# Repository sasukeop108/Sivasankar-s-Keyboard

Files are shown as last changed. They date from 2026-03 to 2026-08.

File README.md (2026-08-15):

# Sivasankar's keyboard
One day, I was thinking about making a custom keyboard which would be suitable for me from scratch but that was too costly. After i joined hackclub's stasis i thought why not to build our keyboard as the stasis event funds us. So i started making a custom 75 percent keyboard from scratch using fusion 360 and kicad. I used the layout keycool 84 which had 84 keys in it.
# Built keyboard


# Layout
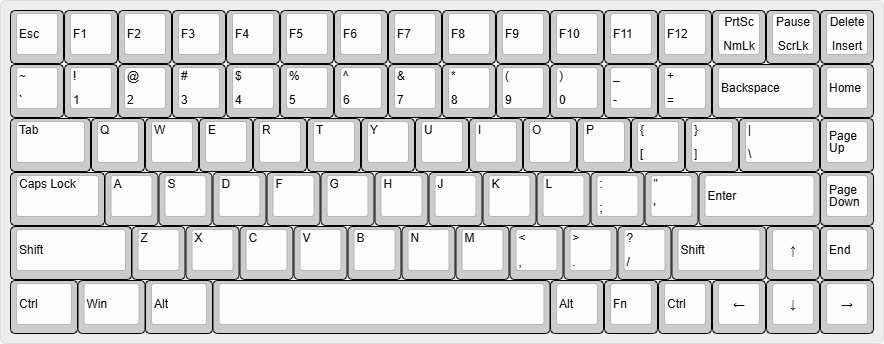
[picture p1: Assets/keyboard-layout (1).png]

# CAD
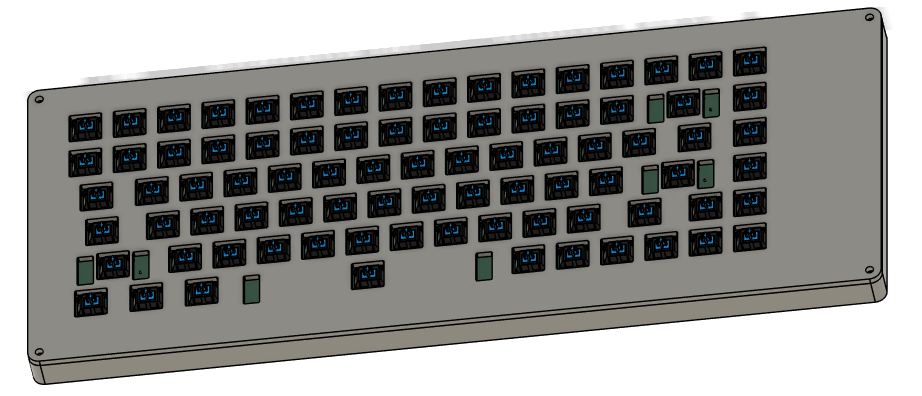
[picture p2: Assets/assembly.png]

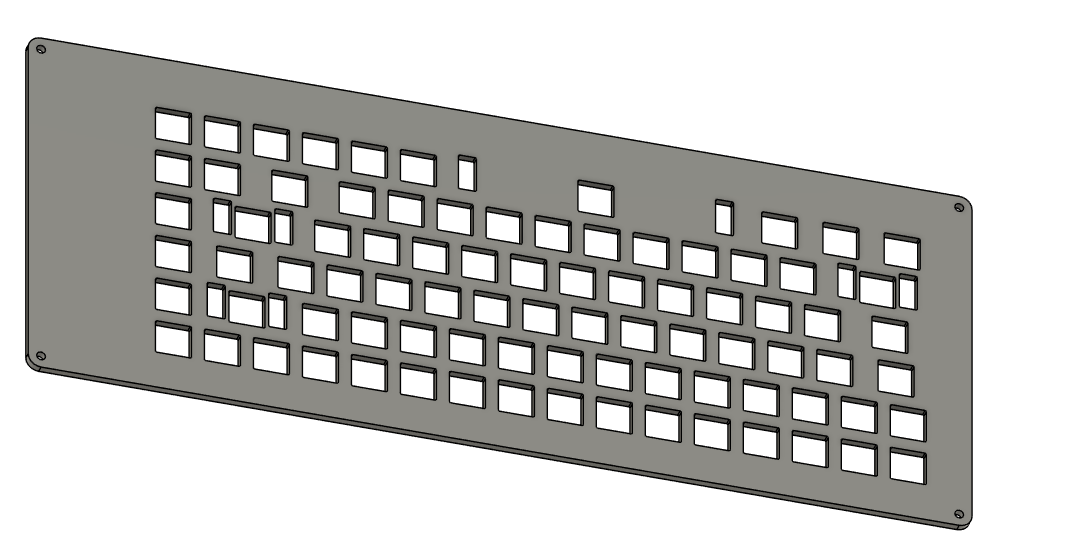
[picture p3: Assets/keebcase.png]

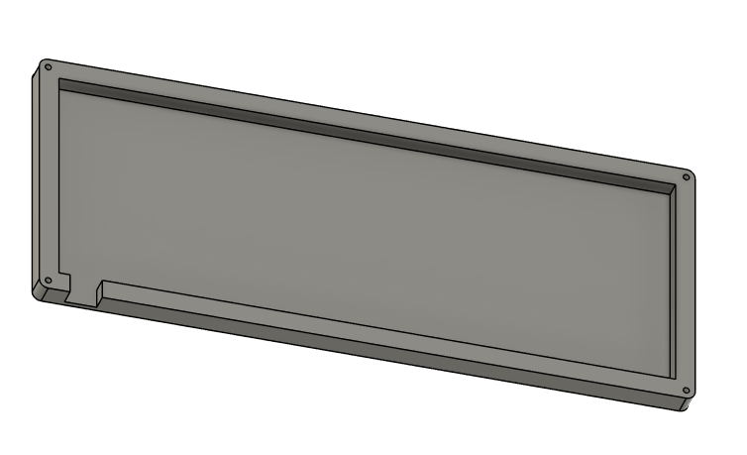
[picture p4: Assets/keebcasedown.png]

# PCB
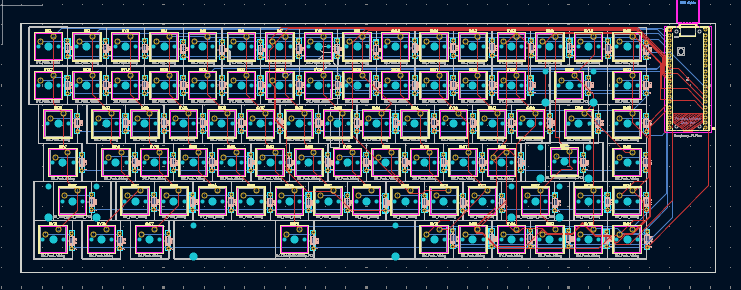
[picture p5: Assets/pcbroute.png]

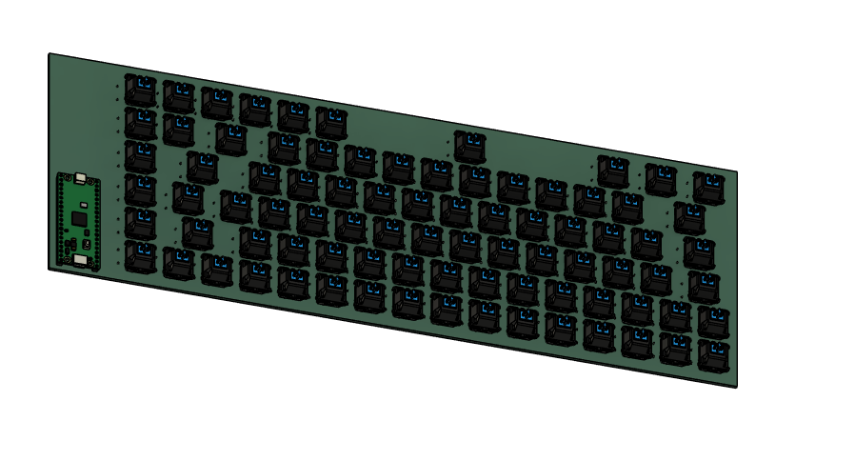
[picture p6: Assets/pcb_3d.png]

# SCHEMATIC
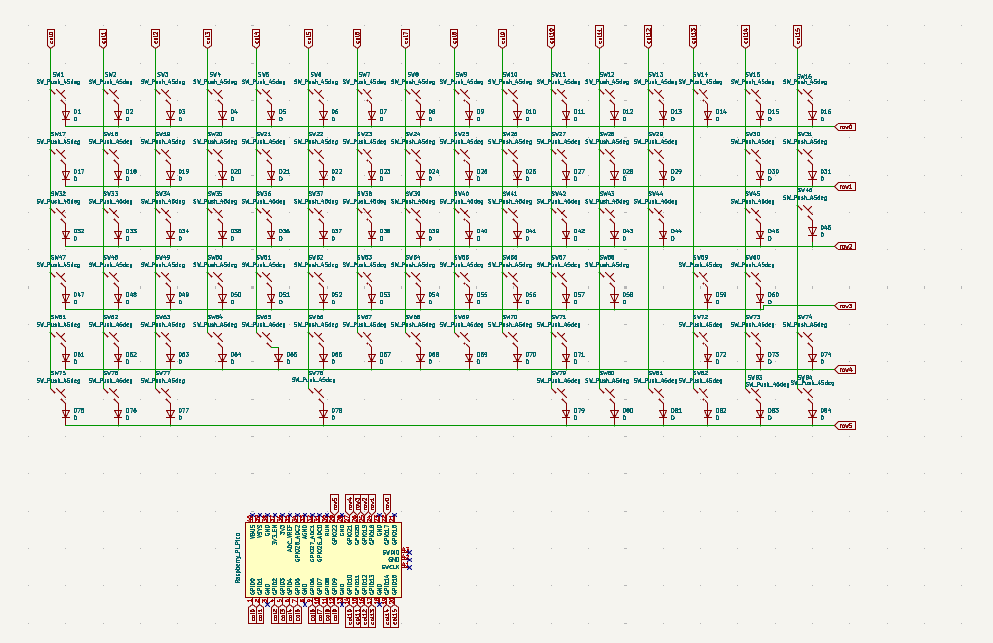
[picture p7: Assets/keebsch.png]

# BOM
| Name | Purpose | Cost Per Item (USD) | Quantity | Total (USD) | Link | Distributor |
| :--- | :--- | :--- | :--- | :--- | :--- | :--- |
| 3d case | for housing keyboard | 8.50 | 1 | 8.50 | | printing legion |
| switches | for input to raspberry pi pico | 2.14 | 9 | 19.26 | [Cosmic Byte](https://www.thecosmicbyte.com/product/gateron-mechanical-switches-compatible-with-cosmic-byte-hot-swappable-keyboards-qty-1pc/) | cosmic byte |
| raspberry pi pico | for controlling everything | 0.00 | 1 | 0.00 | | self sourced |
| custom pcb | for soldering all components on | 40.65 | 1 | 40.65 | | jlcpcb |
| stabilizers | for bigger keycaps | 17.05 | 1 | 17.05 | [StacksKB](https://stackskb.com) | stackskb |
| keycaps | keys for typing | 13.89 | 1 | 13.89 | [StacksKB](https://stackskb.com/store/veekos-gradient-keycaps-cherry-profile-135-keys/) | stackskb |
| **Grand Total** | | | | **99.35** | | |
# Flashing instructions
download the keyboard.py from, the firmware folder and import it into circuit python select the com ports and youre ready to flash the code.

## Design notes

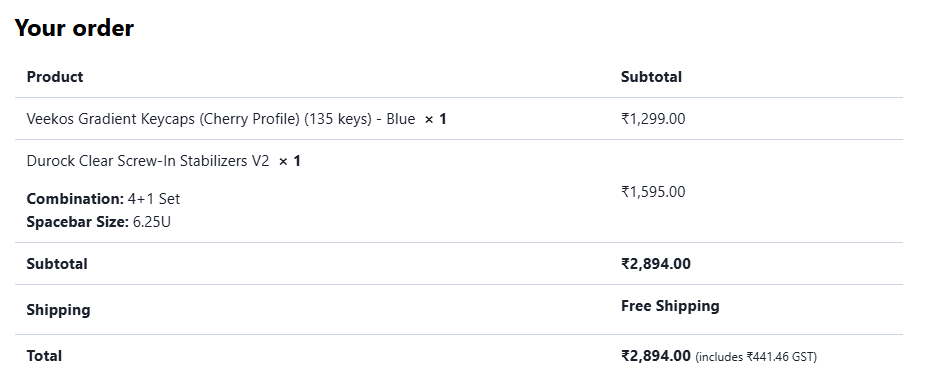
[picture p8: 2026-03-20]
Cart/StacksKB.png

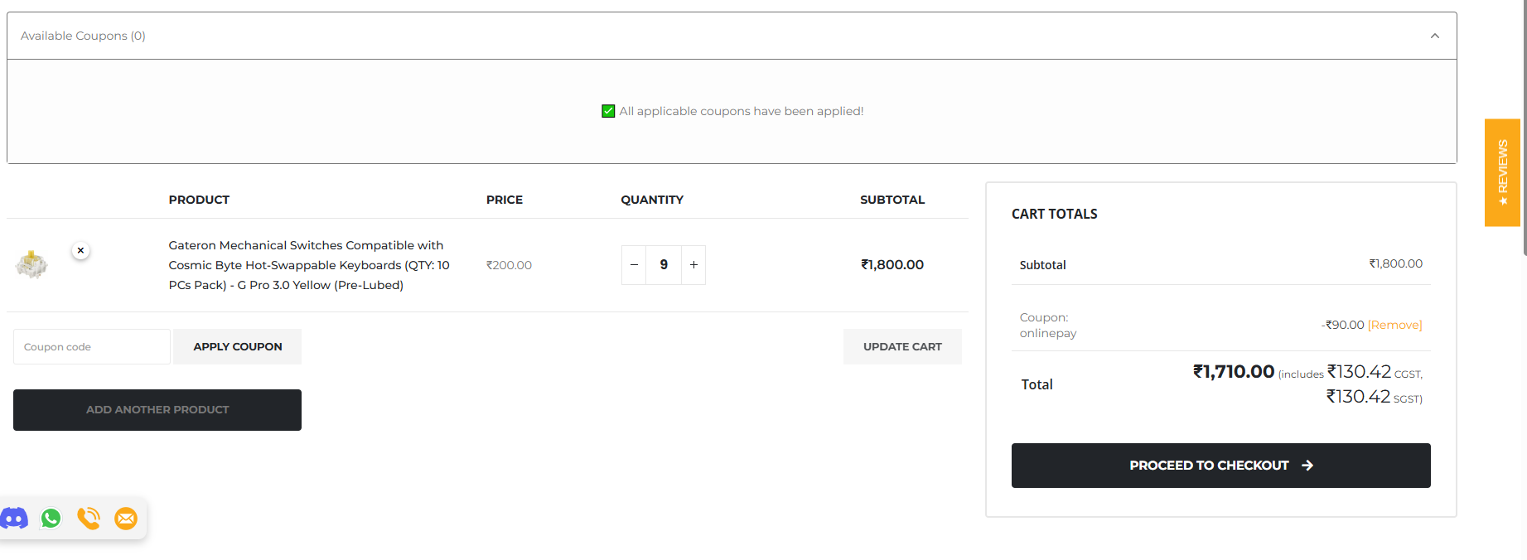
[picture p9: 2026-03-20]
Cart/cosmicbyte.png

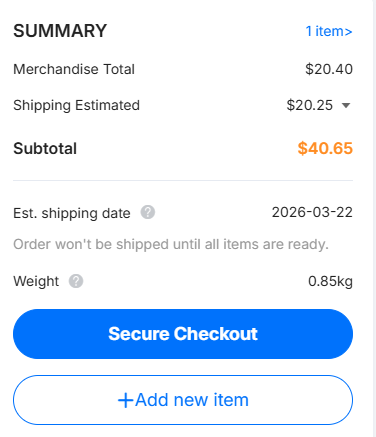
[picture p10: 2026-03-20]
Cart/jlc.png

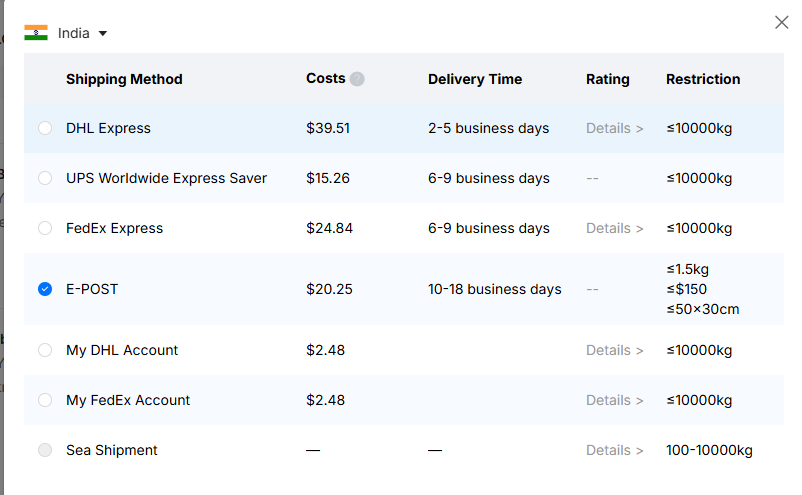
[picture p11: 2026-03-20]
Cart/jlcshipping.png

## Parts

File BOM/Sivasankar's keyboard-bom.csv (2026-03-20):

Name | Purpose | Cost Per Item (USD) | Quantity | Total (USD) | Link | Distributor
3d case | for housing keyboard | 8.50 | 1 | 8.50 |  | printing legion
switches | for input to raspberry pi pico | 2.14 | 9 | 19.26 | https://www.thecosmicbyte.com/product/gateron-mechanical-switches-compatible-with-cosmic-byte-hot-swappable-keyboards-qty-1pc/ | cosmic byte
raspberry pi pico | for controlling everything | 0.00 | 1 | 0.00 |  | sel sourced
custom pcb | for soldering all components on | 40.65 | 1 | 40.65 |  | jlcpcb
stabilizers | for bigger keycaps | 17.05 | 1 | 17.05 | https://stackskb.com/store/durock-clear-screw-in-stabilizers-v2/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 | stackskb
keycaps | keys for typing | 13.89 | 1 | 13.89 | https://stackskb.com/store/veekos-gradient-keycaps-cherry-profile-135-keys/ | stackskb

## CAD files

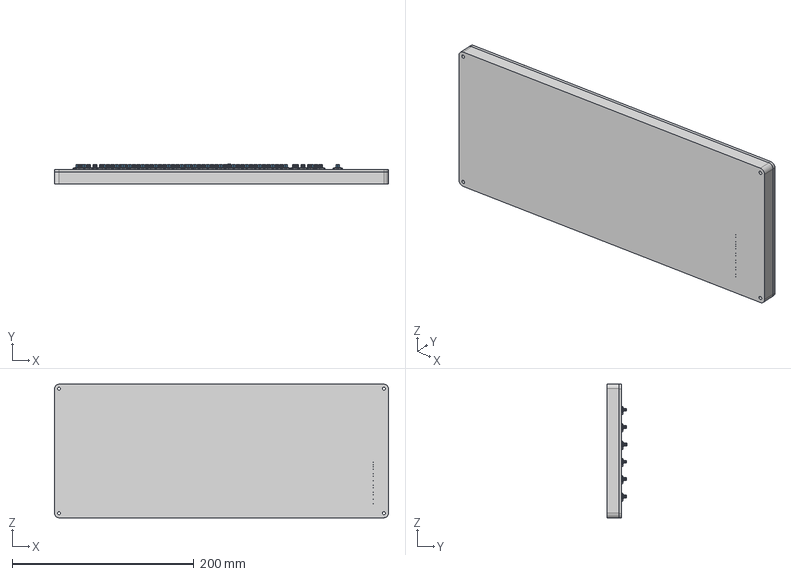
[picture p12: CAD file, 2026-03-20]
CAD/Sivasankar's keyboard (Assembly).step
367.1 x 21.8 x 146.9 mm

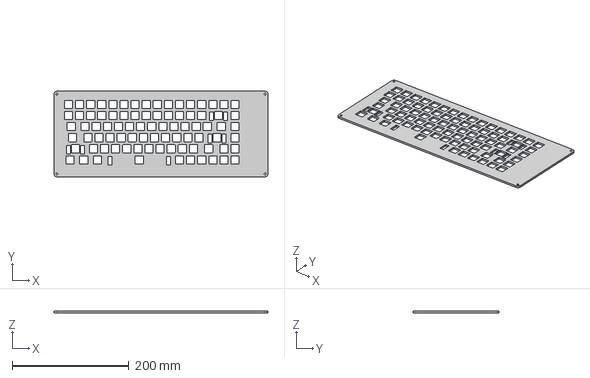
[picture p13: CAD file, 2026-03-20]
Production/sivasankar's keeb top.step
367.0 x 146.8 x 3.00 mm

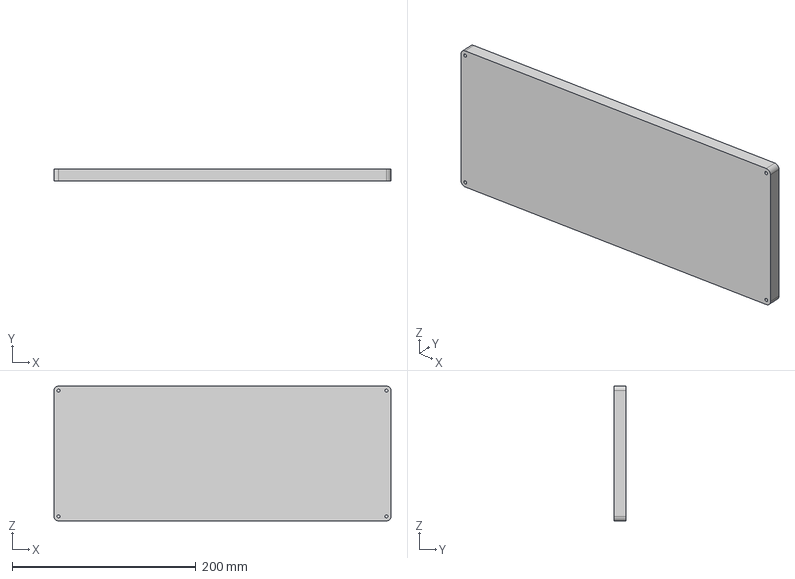
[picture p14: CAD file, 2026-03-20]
Production/case.step
367.0 x 13.0 x 146.8 mm

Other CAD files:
CAD/Sivasankar's keyboard (Assembly).f3z
CAD/casw.f3d
CAD/sivasankar's keeb top.f3d

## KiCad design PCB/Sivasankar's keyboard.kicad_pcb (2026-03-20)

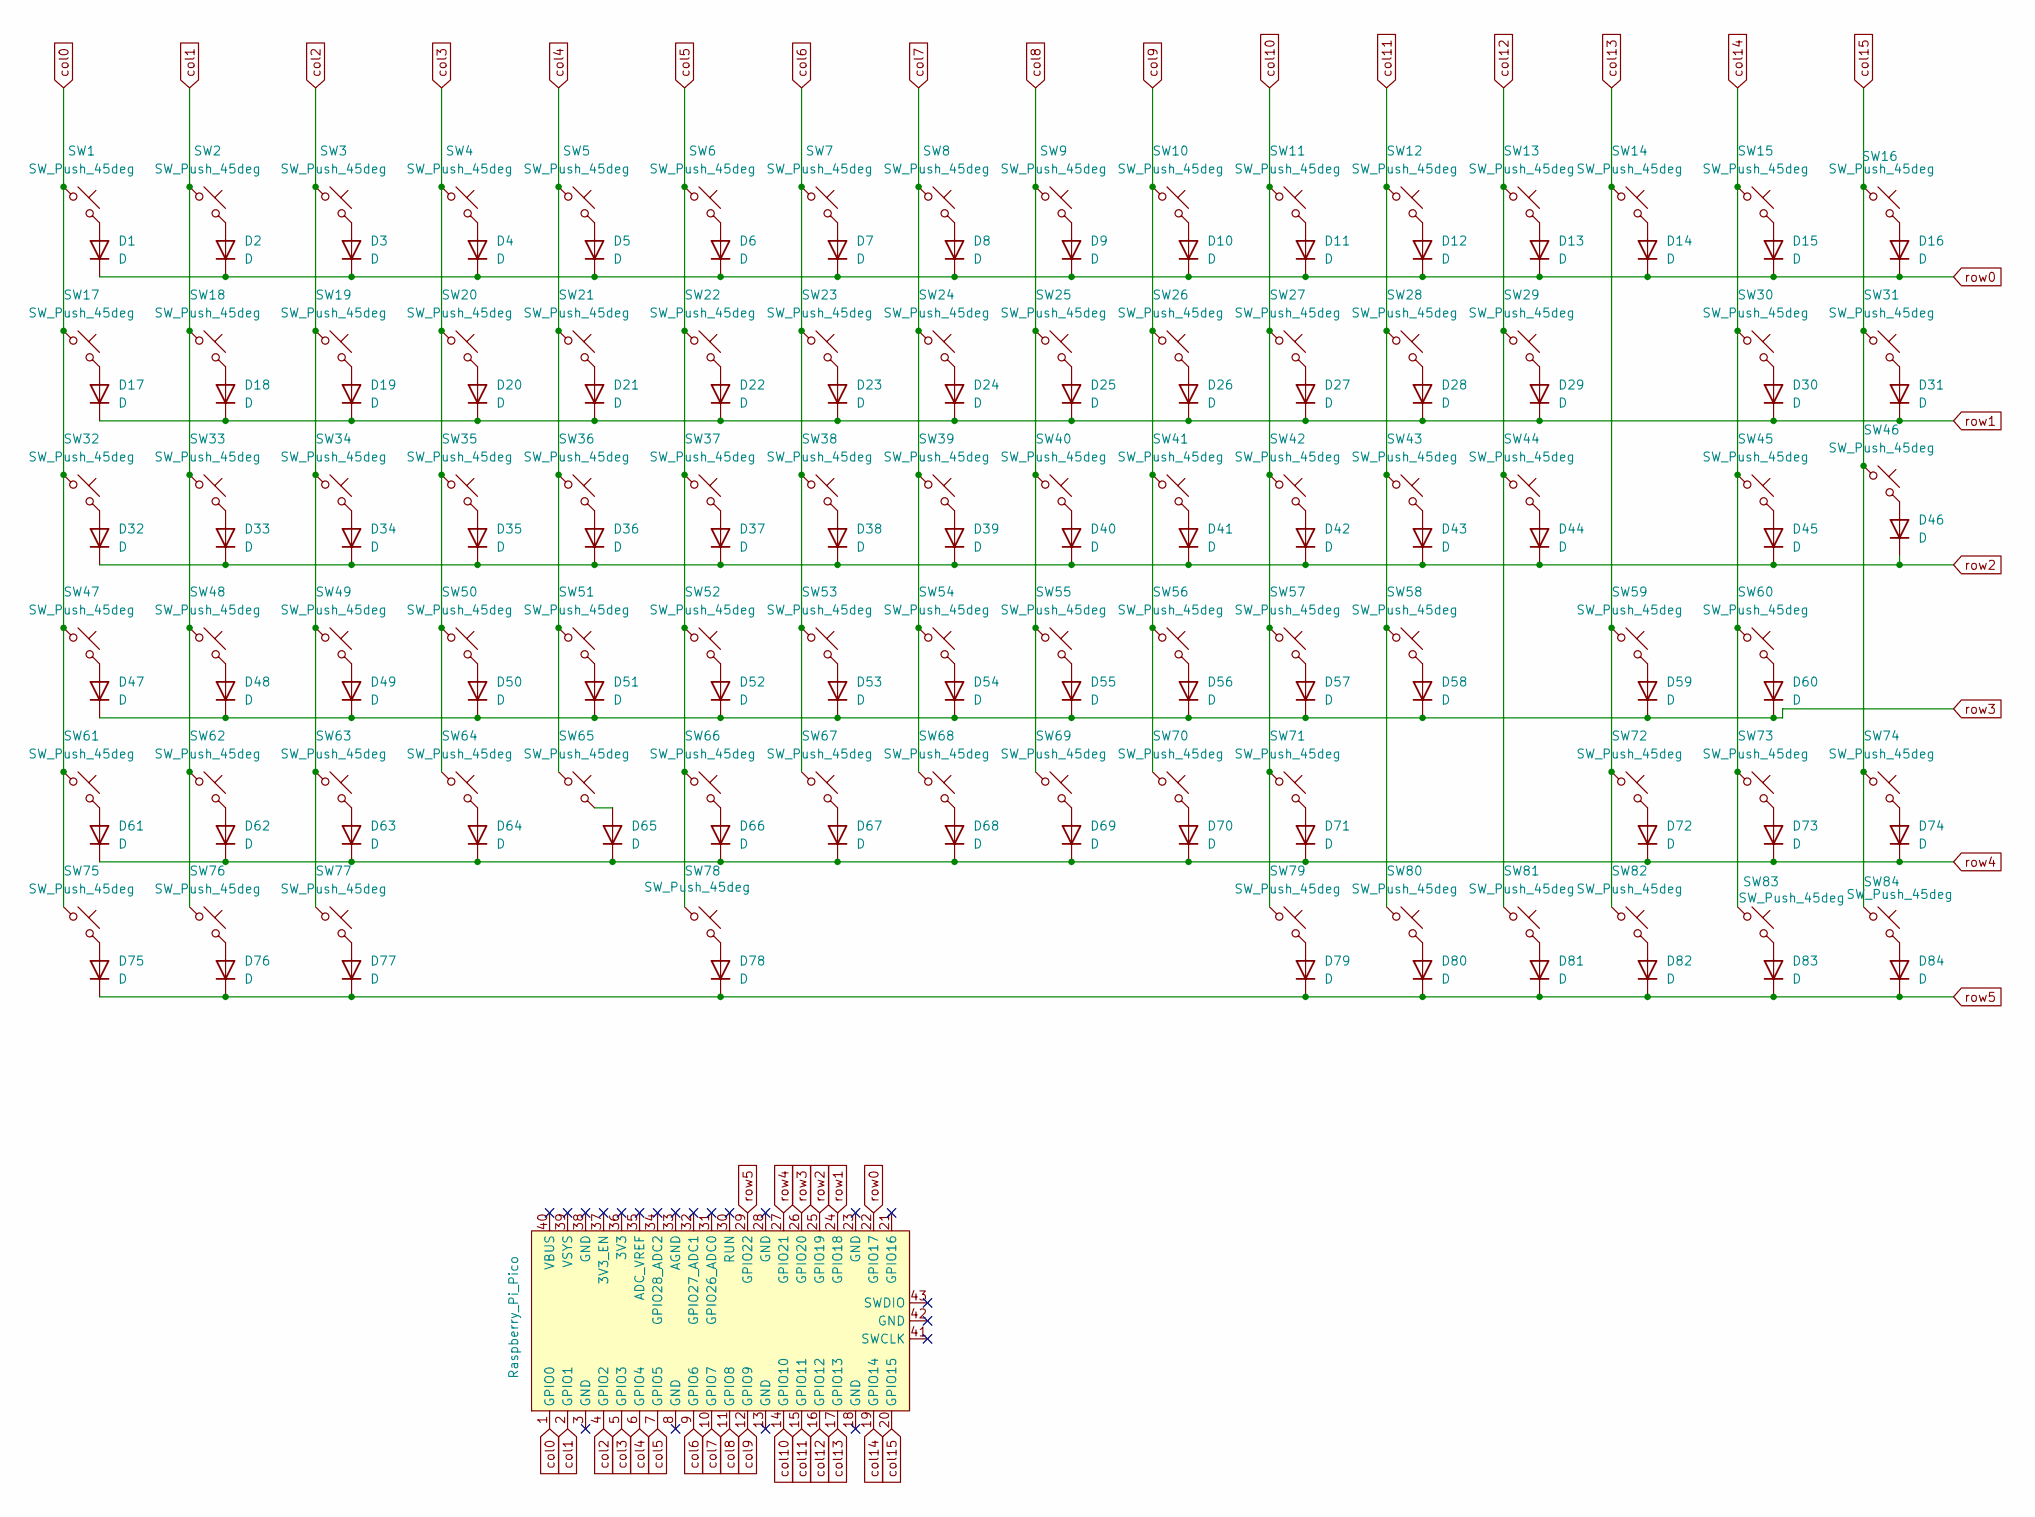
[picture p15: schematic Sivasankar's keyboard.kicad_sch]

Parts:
D1, D2, D3, D4, D5, D6, D7, D8, D9, D10, D11, D12, D13, D14, D15, D16, D17, D18, D19, D20, D21, D22, D23, D24, D25, D26, D27, D28, D29, D30, D31, D32, D33, D34, D35, D36, D37, D38, D39, D40, D41, D42, D43, D44, D45, D46, D47, D48, D49, D50, D51, D52, D53, D54, D55, D56, D57, D58, D59, D60, D61, D62, D63, D64, D65, D66, D67, D68, D69, D70, D71, D72, D73, D74, D75, D76, D77, D78, D79, D80, D81, D82, D83, D84: D; D_DO-35_SOD27_P7.62mm_Horizontal
SW1, SW2, SW3, SW4, SW5, SW6, SW7, SW8, SW9, SW10, SW11, SW12, SW13, SW14, SW15, SW16, SW17, SW18, SW19, SW20, SW21, SW22, SW23, SW24, SW25, SW26, SW27, SW28, SW29, SW30, SW31, SW32, SW33, SW34, SW35, SW36, SW37, SW38, SW39, SW40, SW41, SW42, SW43, SW44, SW45, SW46, SW47, SW48, SW49, SW50, SW51, SW52, SW53, SW54, SW55, SW56, SW57, SW58, SW59, SW60, SW61, SW62, SW63, SW64, SW65, SW66, SW67, SW68, SW69, SW70, SW71, SW72, SW73, SW74, SW75, SW76, SW77, SW78, SW79, SW80, SW81, SW82, SW83, SW84: SW_Push_45deg; SW_Cherry_MX_1.00u_PCB
U1: Raspberry_Pi_Pico; RaspberryPi_Pico_Common_THT

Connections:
unnamed: D1.2 (A), SW1.2
unnamed: D2.2 (A), SW2.2
unnamed: D3.2 (A), SW3.2
unnamed: D4.2 (A), SW4.2
unnamed: D5.2 (A), SW5.2
unnamed: D6.2 (A), SW6.2
unnamed: D7.2 (A), SW7.2
unnamed: D8.2 (A), SW8.2
unnamed: D9.2 (A), SW9.2
unnamed: D10.2 (A), SW10.2
unnamed: D11.2 (A), SW11.2
unnamed: D12.2 (A), SW12.2
unnamed: D13.2 (A), SW13.2
unnamed: D14.2 (A), SW14.2
unnamed: D15.2 (A), SW15.2
unnamed: D16.2 (A), SW16.2
unnamed: D17.2 (A), SW17.2
unnamed: D18.2 (A), SW18.2
unnamed: D19.2 (A), SW19.2
unnamed: D20.2 (A), SW20.2
unnamed: D21.2 (A), SW21.2
unnamed: D22.2 (A), SW22.2
unnamed: D23.2 (A), SW23.2
unnamed: D24.2 (A), SW24.2
unnamed: D25.2 (A), SW25.2
unnamed: D26.2 (A), SW26.2
unnamed: D27.2 (A), SW27.2
unnamed: D28.2 (A), SW28.2
unnamed: D29.2 (A), SW29.2
unnamed: D30.2 (A), SW30.2
unnamed: D31.2 (A), SW31.2
unnamed: D32.2 (A), SW32.2
unnamed: D33.2 (A), SW33.2
unnamed: D34.2 (A), SW34.2
unnamed: D35.2 (A), SW35.2
unnamed: D36.2 (A), SW36.2
unnamed: D37.2 (A), SW37.2
unnamed: D38.2 (A), SW38.2
unnamed: D39.2 (A), SW39.2
unnamed: D40.2 (A), SW40.2
unnamed: D41.2 (A), SW41.2
unnamed: D42.2 (A), SW42.2
unnamed: D43.2 (A), SW43.2
unnamed: D44.2 (A), SW44.2
unnamed: D45.2 (A), SW45.2
unnamed: D46.2 (A), SW46.2
unnamed: D47.2 (A), SW47.2
unnamed: D48.2 (A), SW48.2
unnamed: D49.2 (A), SW49.2
unnamed: D50.2 (A), SW50.2
unnamed: D51.2 (A), SW51.2
unnamed: D52.2 (A), SW52.2
unnamed: D53.2 (A), SW53.2
unnamed: D54.2 (A), SW54.2
unnamed: D55.2 (A), SW55.2
unnamed: D56.2 (A), SW56.2
unnamed: D57.2 (A), SW57.2
unnamed: D58.2 (A), SW58.2
unnamed: D59.2 (A), SW59.2
unnamed: D60.2 (A), SW60.2
unnamed: D61.2 (A), SW61.2
unnamed: D62.2 (A), SW62.2
unnamed: D63.2 (A), SW63.2
unnamed: D64.2 (A), SW64.2
unnamed: D65.2 (A), SW65.2
unnamed: D66.2 (A), SW66.2
unnamed: D67.2 (A), SW67.2
unnamed: D68.2 (A), SW68.2
unnamed: D69.2 (A), SW69.2
unnamed: D70.2 (A), SW70.2
unnamed: D71.2 (A), SW71.2
unnamed: D72.2 (A), SW72.2
unnamed: D73.2 (A), SW73.2
unnamed: D74.2 (A), SW74.2
unnamed: D75.2 (A), SW75.2
unnamed: D76.2 (A), SW76.2
unnamed: D77.2 (A), SW77.2
unnamed: D78.2 (A), SW78.2
unnamed: D79.2 (A), SW79.2
unnamed: D80.2 (A), SW80.2
unnamed: D81.2 (A), SW81.2
unnamed: D82.2 (A), SW82.2
unnamed: D83.2 (A), SW83.2
unnamed: D84.2 (A), SW84.2
col0: SW1.1, SW17.1, SW32.1, SW47.1, SW61.1, SW75.1, U1.1 (GPIO0)
col1: SW2.1, SW18.1, SW33.1, SW48.1, SW62.1, SW76.1, U1.2 (GPIO1)
col2: SW3.1, SW19.1, SW34.1, SW49.1, SW63.1, SW77.1, U1.4 (GPIO2)
col3: SW4.1, SW20.1, SW35.1, SW50.1, SW64.1, U1.5 (GPIO3)
col4: SW5.1, SW21.1, SW36.1, SW51.1, SW65.1, U1.6 (GPIO4)
col5: SW6.1, SW22.1, SW37.1, SW52.1, SW66.1, SW78.1, U1.7 (GPIO5)
col6: SW7.1, SW23.1, SW38.1, SW53.1, SW67.1, U1.9 (GPIO6)
col7: SW8.1, SW24.1, SW39.1, SW54.1, SW68.1, U1.10 (GPIO7)
col8: SW9.1, SW25.1, SW40.1, SW55.1, SW69.1, U1.11 (GPIO8)
col9: SW10.1, SW26.1, SW41.1, SW56.1, SW70.1, U1.12 (GPIO9)
col10: SW11.1, SW27.1, SW42.1, SW57.1, SW71.1, SW79.1, U1.14 (GPIO10)
col11: SW12.1, SW28.1, SW43.1, SW58.1, SW80.1, U1.15 (GPIO11)
col12: SW13.1, SW29.1, SW44.1, SW81.1, U1.16 (GPIO12)
col13: SW14.1, SW59.1, SW72.1, SW82.1, U1.17 (GPIO13)
col14: SW15.1, SW30.1, SW45.1, SW60.1, SW73.1, SW83.1, U1.19 (GPIO14)
col15: SW16.1, SW31.1, SW46.1, SW74.1, SW84.1, U1.20 (GPIO15)
row0: D1.1 (K), D2.1 (K), D3.1 (K), D4.1 (K), D5.1 (K), D6.1 (K), D7.1 (K), D8.1 (K), D9.1 (K), D10.1 (K), D11.1 (K), D12.1 (K), D13.1 (K), D14.1 (K), D15.1 (K), D16.1 (K), U1.22 (GPIO17)
row1: D17.1 (K), D18.1 (K), D19.1 (K), D20.1 (K), D21.1 (K), D22.1 (K), D23.1 (K), D24.1 (K), D25.1 (K), D26.1 (K), D27.1 (K), D28.1 (K), D29.1 (K), D30.1 (K), D31.1 (K), U1.24 (GPIO18)
row2: D32.1 (K), D33.1 (K), D34.1 (K), D35.1 (K), D36.1 (K), D37.1 (K), D38.1 (K), D39.1 (K), D40.1 (K), D41.1 (K), D42.1 (K), D43.1 (K), D44.1 (K), D45.1 (K), D46.1 (K), U1.25 (GPIO19)
row3: D47.1 (K), D48.1 (K), D49.1 (K), D50.1 (K), D51.1 (K), D52.1 (K), D53.1 (K), D54.1 (K), D55.1 (K), D56.1 (K), D57.1 (K), D58.1 (K), D59.1 (K), D60.1 (K), U1.26 (GPIO20)
row4: D61.1 (K), D62.1 (K), D63.1 (K), D64.1 (K), D65.1 (K), D66.1 (K), D67.1 (K), D68.1 (K), D69.1 (K), D70.1 (K), D71.1 (K), D72.1 (K), D73.1 (K), D74.1 (K), U1.27 (GPIO21)
row5: D75.1 (K), D76.1 (K), D77.1 (K), D78.1 (K), D79.1 (K), D80.1 (K), D81.1 (K), D82.1 (K), D83.1 (K), D84.1 (K), U1.29 (GPIO22)

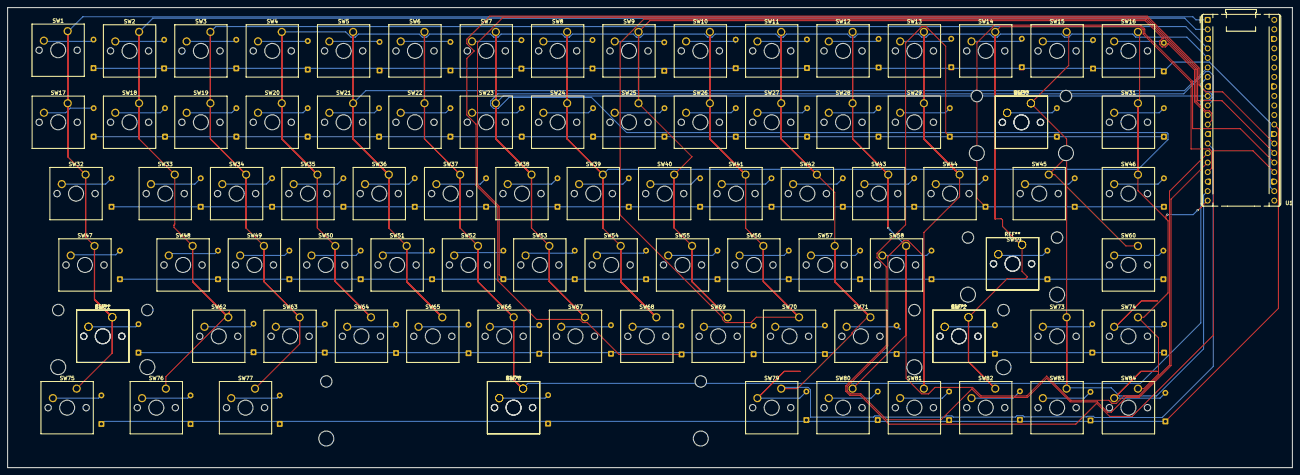
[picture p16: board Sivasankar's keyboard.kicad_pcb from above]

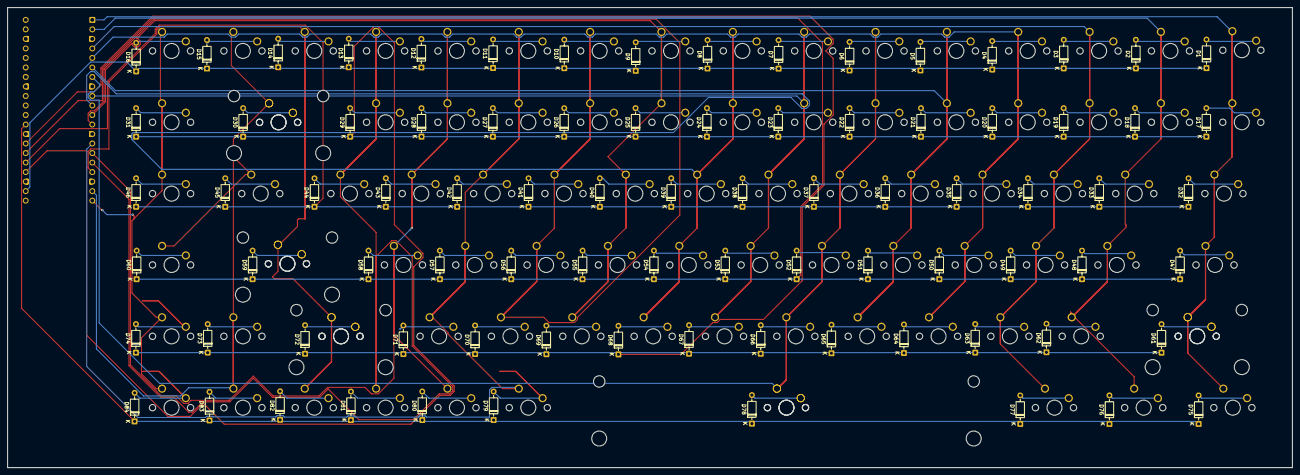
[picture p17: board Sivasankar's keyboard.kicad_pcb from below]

Board: 2 copper layers, 343.0 x 122.8 mm, 169 parts (84 on the bottom side), 106 nets.

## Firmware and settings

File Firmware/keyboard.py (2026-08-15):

from kmk.kmk_keyboard import KMKKeyboard
from kmk.keys import KC
from kmk.scanners import DiodeOrientation
from kmk.modules.layers import Layers
import board

keyboard = KMKKeyboard()

keyboard.modules.append(Layers())

keyboard.col_pins = (
    board.GP0,  board.GP1,  board.GP2,  board.GP3,
    board.GP4,  board.GP5,  board.GP6,  board.GP7,
    board.GP8,  board.GP9,  board.GP10, board.GP11,
    board.GP12, board.GP13, board.GP14, board.GP15,
)

keyboard.row_pins = (
    board.GP17, board.GP18, board.GP19,
    board.GP20, board.GP21, board.GP22,
)

keyboard.diode_orientation = DiodeOrientation.COL2ROW

keyboard.keymap = [
    [
    
        KC.ESC,  KC.F1,   KC.F2,   KC.F3,   KC.F4,   KC.F5,   KC.F6,   KC.F7,
        KC.F8,   KC.F9,   KC.F10,  KC.F11,  KC.F12,  KC.PSCR, KC.PAUS, KC.DEL,
    
        KC.GRV,  KC.N1,   KC.N2,   KC.N3,   KC.N4,   KC.N5,   KC.N6,   KC.N7,
        KC.N8,   KC.N9,   KC.N0,   KC.MINS, KC.EQL,  KC.NO,   KC.BSPC, KC.HOME,

        KC.TAB,  KC.Q,    KC.W,    KC.E,    KC.R,    KC.T,    KC.Y,    KC.U,
        KC.I,    KC.O,    KC.P,    KC.LBRC, KC.RBRC, KC.NO,   KC.BSLS, KC.PGUP,

        KC.CAPS, KC.A,    KC.S,    KC.D,    KC.F,    KC.G,    KC.H,    KC.J,
        KC.K,    KC.L,    KC.SCLN, KC.QUOT, KC.NO,   KC.ENT,  KC.PGDN, KC.NO,

        KC.LSFT, KC.Z,    KC.X,    KC.C,    KC.V,    KC.B,    KC.N,    KC.M,
        KC.COMM, KC.DOT,  KC.SLSH, KC.NO,   KC.RSFT, KC.UP,   KC.END,  KC.NO,

        KC.LCTL, KC.LGUI, KC.LALT, KC.NO,   KC.NO,   KC.SPC,  KC.NO,   KC.NO,
        KC.NO,   KC.NO,   KC.RALT, KC.MO(1),KC.RCTL, KC.LEFT, KC.DOWN, KC.RGHT,
    ],
   
    [
        KC.TRNS, KC.TRNS, KC.TRNS, KC.TRNS, KC.TRNS, KC.TRNS, KC.TRNS, KC.TRNS,
        KC.TRNS, KC.TRNS, KC.TRNS, KC.TRNS, KC.TRNS, KC.TRNS, KC.TRNS, KC.TRNS,

        KC.TRNS, KC.TRNS, KC.TRNS, KC.TRNS, KC.TRNS, KC.TRNS, KC.TRNS, KC.TRNS,
        KC.TRNS, KC.TRNS, KC.TRNS, KC.TRNS, KC.TRNS, KC.TRNS, KC.TRNS, KC.TRNS,

        KC.TRNS, KC.TRNS, KC.TRNS, KC.TRNS, KC.TRNS, KC.TRNS, KC.TRNS, KC.TRNS,
        KC.TRNS, KC.TRNS, KC.TRNS, KC.TRNS, KC.TRNS, KC.TRNS, KC.TRNS, KC.TRNS,

        KC.TRNS, KC.TRNS, KC.TRNS, KC.TRNS, KC.TRNS, KC.TRNS, KC.TRNS, KC.TRNS,
        KC.TRNS, KC.TRNS, KC.TRNS, KC.TRNS, KC.TRNS, KC.TRNS, KC.TRNS, KC.TRNS,

        KC.TRNS, KC.TRNS, KC.TRNS, KC.TRNS, KC.TRNS, KC.TRNS, KC.TRNS, KC.TRNS,
        KC.TRNS, KC.TRNS, KC.TRNS, KC.TRNS, KC.TRNS, KC.TRNS, KC.TRNS, KC.TRNS,

        KC.TRNS, KC.TRNS, KC.TRNS, KC.TRNS, KC.TRNS, KC.TRNS, KC.TRNS, KC.TRNS,
        KC.TRNS, KC.TRNS, KC.TRNS, KC.TRNS, KC.TRNS, KC.TRNS, KC.TRNS, KC.TRNS,
    ],
]

if __name__ == '__main__':
    keyboard.go()
